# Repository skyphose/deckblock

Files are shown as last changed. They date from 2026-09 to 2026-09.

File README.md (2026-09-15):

# deckblock

a dice and counter tray that lives INSIDE a top-opening deck box, alongside the cards.
one parametric source, two variants.

it was made to fit an ultimate guard boulder 100+. thats the box i own, and every
dimension in it came off that box or off the sleeves that go in it. its also universal,
which is arithmetic rather than a claim: width and height come off the card footprint,
and thats the same in every standard-size deck box. only depth varies between them.

the variants answer "do you carry a coin?", not "which game do you play". the layouts
were named after games for three releases and it was always slightly a lie - nothing in
either is game-specific. people picked the wrong one because they picked by the name on
the box rather than by what they actually carry.

fit spec: the slab is 67 x 91 x 18.6 mm. it drops into any top-opening deck box with an
interior at least 67 mm wide, 91 mm tall, with 19 mm of depth to spare.

the height is taken from the SLEEVE rather than the box. an ultimate guard katana
standard sleeve is 66 x 91 mm, and every deck in the box is that tall. so the test is
whether your sleeved cards stand up in it - if they do, so does this. taking the height
from the sleeve also puts the slab's top edge level with the top of the cards rather than
below them. it doesnt sink away from the opening.

the width is that sleeve plus 1 mm (`over_w`). the slab only has to fit the box, not sit
beside a card, and every millimeter there lands in the cavity field. that makes
width the one dimension still bounded by the REPORTED box interior rather than a
published figure. 0.75 mm of clearance per side, so a box 1 mm narrower than reported
still fits and one 1.5 mm narrower doesnt. set `over_w = 0` to sit exactly on the sleeve.

width and height are set by the card footprint and so are effectivley constant across
standard-size boxes. only depth varies. dimensioned around an ultimate guard boulder 100+
(interior about 68.5 x 67.5 x 93 mm), which is where the fit gaps come from. that box is
the only one whose interior figure has been looked up, and even that one is a reported
number rather than an official spec. treat the three numbers above as the thing to
measure against, not the brand.

| variant | holds | slab depth | card depth left |
|---|---|---|---|
| `nocoin` | 6 x 16 mm d6 + a 43.8 mm open bay for tokens | 18.6 mm | 48.9 mm |
| `coin` | 7 x 16 mm d6 + a ⌀38 mm flip-coin well, no bay | 18.6 mm | 48.9 mm |

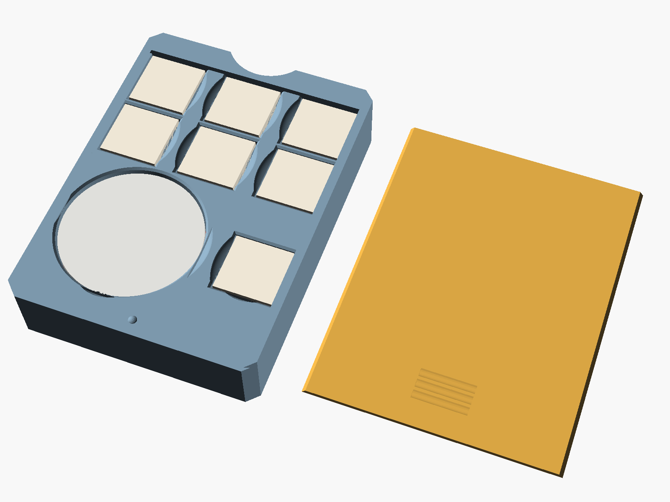
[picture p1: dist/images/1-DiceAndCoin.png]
the coin variant


## how it works

a slab that spans the full interior width and height of the case but only about 19 mm
of its roughly 67 mm depth. because its captured on all four sides by the case walls, it
cant shift, tip or rattle. a sliding lid encloses the contents.

the lid exits the BOTTOM edge. once the slab is seated in the case, the floor of the deck
box sits across that edge and blocks the lid. it can only come off once you lift the
slab out, using the finger scoop in the top rail.

```
                 slab           +-- 48.9 mm left for cards --+
   box wall  | <-18.6 mm-> |    |                              |  box wall
             |[d6][d6][d6] |    |   sideboard                  |
             |[d6][d6][d6] |    |                              |
             | open bay    |    |                              |
```

## the depth budget is the whole design

18.6 mm is the practical floor for an enclosed 16 mm die - the die itself is 86% of it:

```
  0.8  floor (with a push-out hole under each cavity)
 16.3  cavity depth      <- 16.0 of this is the die
  1.5  lid + its groove, running out to the top face
 -----
 18.6  mm
```

every millimeter added here is a millimeter taken from the card stack. thats why the
round wells are 16.3 mm deep and no deeper: a deeper well buys counter capacity you
wont use, and a double-sleeved 60-card deck needs roughly 45 mm. both variants therefore
land on the same 18.6 mm.

pick by whats in your bag, not by which game you play - nothing in either layout is
game-specific. mtg and riftbound players almost always want the no-coin one. pokemon
players almost always want the coin one.

the coin variant has MORE dice, not fewer. a round well's diameter sets the height of the
whole band it sits in. so the coin's band is 38.8 mm tall and leaves 22.2 mm of the 61 mm
interior beside it - exactly enough for a seventh die rather than dead space. the coin
costs the bay, not the dice.

there used to be a fourth line here: 1.4 mm of "retaining lip above the groove". it was
doing nothing. the groove is a DOVETAIL. the lid is trapezoidal and wide at its base, so
what stops it lifting out is the taper of the groove beside it, not material on top of
it. running the groove out to the top face costs nothing srtucturally, takes 1.4 mm
straight off the slab, and brings the lid flush with the frame.

a polyhedral die is cheaper than it looks. one resting on a face is only 0.795 x its
vertex-to-vertex width tall. so a 20 mm d20 in a custom layout stands 15.9 mm and clears
the standard 16.3 mm well without deepening anything. if you build a custom profile
around a d20, use `well(d20_size, d20_depth)` - `d20_depth` applies that rule for you
instead of the naive full width.

## the pokemon coin well

this was wrong for a long time. worth recording. the well was built around
`coin_d = 26.0`, assumed, not looked up. official pokemon coins run 29.8-51.6 mm. the
common modern flip coin is the 34 mm "large", the bigger authorized collectible is 38 mm,
and 25 mm compact ones and 51 mm jumbos sit at the extremes. a 26.8 mm well took only the
smallest of them, so for most people the coin wouldnt go in.

its now built for `coin_d = 38.0` - a ⌀38.8 mm well, which swallows every size below it:

| coin | ⌀ | fits |
|---|---|---|
| pokemon compact flip coin | ~25 mm | yes |
| us quarter | 24.26 mm | yes |
| pokemon LARGE flip coin (the common one) | 34 mm | yes |
| pokemon large collectible | 38 mm | yes |
| us half dollar | 30.61 mm | yes |
| pokemon jumbo | 51 mm | no - see below |

### what the coin costs

a round well's DIAMETER sets the height of the whole band it sits in. so a 38.8 mm well
is expensive twice over: its 38.8 mm tall, and it leaves only 22.2 mm of the 61 mm
interior beside it. two consequences:

- the coin gets one companion, not two. coin + two ⌀13.8 counter wells comes to 66.4 mm
  in a 61 mm interior - impossible at any wall thickness. its paired with the LARGE
  counter well rather than a small one, because that uses the leftover width better: a
  4.4 mm gap instead of 8.4 mm of dead space.
- the small counter well moved up to join the dice, whose band is only 16.8 mm tall and
  had width going spare. both counter sizes survive. nothing was dropped.

measured, at `div_wall = 1.6`:

| layout | bay | tightest gap | |
|---|---|---|---|
| `[small, d6, d6]` / `[coin, large]` | 15.8 mm | 4.4 mm | shipped |
| `[large, d6, d6]` / `[coin, small]` | 14.8 mm | 4.8 mm | 8.4 mm of dead width |
| `[small, lg, d6]` / `[coin, d6]` | 14.8 mm | 5.4 mm | loses a die |
| `[large, d6, d6]` / `[coin, small, small]` | 17.9 mm | -2.7 mm | impossible |

the bay pays for it: 25.9 mm before, 15.8 mm now. a 25.4 mm status marker no longer lies
flat in it. thats the delliberate trade - a coin well that fits the coin most people own
beats a bay sized for a marker you could keep in the open.

### jumbo coins cant be housed

a 51 mm jumbo needs a 51.8 mm well. that exceeds the tallest band the slab can hold once
the dice row and the bay's bottom wall are accounted for. it doesnt fit loose in the bay
either - the largest bay any layout can offer is 41.9 mm. nothing in a 67 x 91 slab takes
one. if you own a jumbo, it lives outside the insert.

### internal dividers run thinner than the perimeter

`div_wall = 1.6` separates the two bands, against `wall = 2.5` for the outer shell. the
perimeter cant thin, the lid groove already cuts 1.2 mm into it and leaves 1.3 mm. a
divider between two cavities carries no load, so it buys 0.9 mm of bay.

one divider is excluded: the last band's gap to the bay carries the detent bump, whose
footprint is 2.30 mm across. on a 1.6 mm divider the dome would overhang its own wall
and need support, so that gap stays at `wall`.

### what this insert deliberately doesnt do

some games want a second card group at the table - riftbound's rune deck and battlefields
are the clearest case. the obvious idea is a card slot in the slab for them. it cant be
done in this case. the slab is 91 mm tall, exactly a sleeve, and a sleeved standard card
is the same 91 mm. the cards are 3 mm too tall for any slot the slab could contain, in
any orientation. sixteen sleeved cards also want about 11 mm of the depth budget, which
is well over half the 18.6 mm the whole insert gets. keep the runes and battlefields
banded in the main card compartmnet.

## measure before you print

theres no test print at this size to fall back on, so the numbers have to be right up
front. two of them arent measurements:

- the case interior (68.5 x 67.5 x 93 mm) is a widely-reported figure, not an official
  one. check yours before committing to a 3-hour body.
- the counter diameters are plausible values for common accessories, not calipered
  readings of yours.

everything that governs fit is a single named parameter at the top of `deckblock.scad`,
so a miss is a one-number change and a re-render:

| symptom | change |
|---|---|
| dice too tight / too loose | `die_clearance` (0.8 total, ±0.2) |
| counters too tight / too loose | `well_clearance` (0.8 total, ±0.2) |
| counters are the wrong size | `ctr_small_d` / `ctr_large_d` / `coin_d` / `d20_size` |
| lid binds / too loose | `lid_side_clearance` (0.5 total, ±0.2) |
| lid rattles vertically | `lid_vert_clearance` (0.3) |
| detent too weak / too strong | `detent_h` (0.60), see below. set to 0 to remove it |

one clearance parameter governs every cell of a kind: `die_clearance` for square pockets,
`well_clearance` for round wells. so if your SMALLEST counters bind, thats
`well_clearance`, not the layout.

the lid is the cheap part to print: about 20 minutes and 5.8 cm³. it wont tell you
whether the slab fits your case. it does tell you whether the groove clearances and the
detent are right, since its the same extrusion on every profile.

## rendering

```sh
./render.sh              # both variants -> stl/<variant>/ + preview_<variant>.png
./render.sh coin         # just one
```

or open `deckblock.scad` in the openscad gui and pick `variant` in the customizer panel.
installed here via `brew install --cask openscad@snapshot` (the stable `openscad` cask
is disabled on macos - it fails the gatekeeper check).

## print settings

print FLAT, open side up, exactly as the stl is oriented. verified on every body: zero
downward-facing facets steeper than 45°, and the only overhang on a lid is its 2.87 mm²
detent dimple. no supports anywhere.

| | body | lid |
|---|---|---|
| layer height | 0.20 mm | 0.16 mm |
| walls | 3 | 4 |
| infill | 15% gyroid | 100% |
| supports | none | none |

solid volumes:

| variant | body | lid |
|---|---|---|
| `nocoin` | 31.6 cm³ | 6.3 cm³ |
| `coin` | 50.7 cm³ | 6.3 cm³ |

down 12% across the bodies from a space-saving pass. the top rail cut from 10 mm to 7,
the floor from 1.0 to 0.8, and every divider BETWEEN two bands thinned from `wall` to
`div_wall`. each of those also hands the space back to the bay.

with the settings above expect roughly 24-30 g / 2.5-3 h for the nocoin body and about
7 g / 20 min for a lid. scale the coin body by volume and confirm in orca.

the only feature on any part that overhangs is the lid's single 0.35 mm detent dimple
(2.87 mm², measured, on every profile). it bridges over about 2.9 mm in about three
layers and needs no support. every BODY measures exactly 0.00 mm² of unsupported facet.
the pinch notches keep it that way by coonstruction: theyre cut downward from the cavity
mouth, so nothing is ever left spanning over one.

tightest wall: 3.3 mm, between the coin well and its neighbor in the `coin` variant's
third band. thats eight perimeters at 0.4 mm and it thickens immediately either side of
the tangent line. nothing in any shipped profile is thinner.

## one lid fits both

both lids are the SAME file - identical md5, not merely similar, and its checked rather
than assumed: `tools/build_all.sh` compares the md5s on every build.

they used to differ by the position of one dimple. the detent bump sat on the divider
between the last band and the bay, and that divider lands somewhere different in every
layout. any lid would slide in any body, but only its own would click.

the detent is now anchored to the BOTTOM wall, the one piece of solid material every
layout has in the same place, at `detent_y = 4.0`. the lid no longer references the band
list at all, so `insert_lid()` doesnt take one.

the bottom wall is only `wall` thick. that isnt enough to seat the bump and still keep
the lid's mating dimple clear of the lid's open end. so a small boss tihckens it locally:
11 mm wide, reaching 3 mm into the bay. that costs about 0.5 cm³ and a sliver of the
bay's bottom edge - a fair price for one lid instead of three. the lid's grip grooves
moved from y = 4 to y = 8 to stay clear of the dimple, which sits at y = 3.5.

## getting things back out

a pocket sized to hold a die also holds onto it. two features fix that, and both are
sized by rule rather than by eye.

### push-out holes

a hole through the floor behind every cavity, so you push a die or a counter stack out
from behind with a fingertip instead of picking at it.

the hole is sized from the cavity, not to a fixed number. it used to be capped at 14 mm,
so the hole behind a ⌀38.8 mm coin well was the same size as the one behind a ⌀17.8 mm
counter well. the coin sat on a 12.4 mm ledge with a fingertip-sized hole in the middle
of it. you could press the coin, but not tip it. now:

```
hole = min( cavity × pushout_frac ,  cavity − 2 × pushout_ledge )
```

`pushout_frac = 0.80` scales the hole with the cavity. `pushout_ledge = 1.6` is a floor
that takes over on small cavities, where the fraction alone would leave too little
material.

| cavity | old | new | ledge under contents | limited by |
|---|---|---|---|---|
| ⌀13.8 small counter well | 10.6 | 10.6 | 1.20 mm | ledge |
| 16.8 mm d6 pocket | 13.6 | 13.44 | 1.28 mm | proportion |
| ⌀17.8 large counter well | 14.0 | 14.24 | 1.38 mm | proportion |
| ⌀20.8 vp die well | 14.0 | 16.64 | 1.68 mm | proportion |
| ⌀38.8 coin well | 14.0 | 31.04 | 3.48 mm | proportion |

`pushout_d` survives as an optional absolute cap, deefaulting to 0 (none).

nothing can fall through, because the contents are captured sideways by the cavity
walls. a 16 mm die over a 13.44 mm hole still rests on all four corners of its face and
can only move ±0.4 mm. a 38 mm coin over a 31.04 mm hole keeps 3.5 mm of ledge all the
way round.

### pinch cutouts

a dish taken out of the divider beside each cavity. it works WITH the push-out hole
rather than instead of it. push the die up from behind, and the dish is what lets you
get a finger onto its side and catch it.

the shape is a segment of a large circle, not a round-bottomed slot. `notch_arc = 60`
sets how much of that circle is used, a sixth. the radius follows from the bite, so the
sweep stays long and smooth instead of becoming a tight bowl. `notch_depth = 4.5` is how
far it reaches down the side of the die.

each edge is sized against the divider its actually cutting. a divider between two
cavities is bitten from both sides, so each side takes half the spare material. a divider
facing the open bay is bitten once and takes all of it. every divider necks to exactly
`notch_min_wall = 1.2` mm at the notch, whatever it started at. thats the most the cut
can take without going thinner than one number you control.

in practice the side edges, cut into 3.3-6.8 mm dividers, get bites of 1.05-2.2 mm. the
cross-band edges sit on the 1.6 mm `div_wall` divider and would get 0.2 mm, which is a
scratch rather than a grip. so dishes below 0.3 mm arent generated at all. thats the
deliberate trade for thin dividers: the space goes to the bay, and the grip lives on the
side edges.

two properties worth knowing:

- they cant introduce an overhang. the dish is an ellipsoid whose center sits
  `notch_ease` ABOVE the cavity mouth. every scrap of material is below the mouth, hence
  below the center, so every cut surface faces upward. thats also what eases the rim
  instead of leaving a 90° lip. every body measures 0.00 mm² unsupported.
- they cant breach a wall. the full set is clipped to the divider field, inside the
  outer walls and below the top rail. a notch that would break out erases itself
  instead of being a bug. each dish is aditionally clipped to its own side of the edge,
  so it cant reach across a cavity and nibble the divider opposite.

the subtree is wrapped in `render()`. without it the preview's csg normalizer explodes on
the clipped dishes and gives up. it makes no difference to the exported geometry.

set `pinch_notch = false` to omit them entirely.

## layouts

each profile is a stack of bands, laid out top-down under the finger rail. whatever
height is left at the bottom becomes the open bay. within a band, gaps are derived to
fill the interior width.

```
band = [ [cell, cell, ...], gap_after, cell_gap ]
cell = ["sq", w, h, depth]     rect pocket (dice, card-shaped markers)
     | ["rd", d, d, depth]     round well  (counters, coins, a d20)
```

so a new layout is a few lines. set `variant = "custom"` and edit `custom_bands`:

```scad
custom_bands = [
    [[ d6(), d6(), d6() ],                                 div_wall, 0],
    [[ well(ctr_small_d, well_depth), well(coin_d, 16.3) ], wall,    0],
];
```

`cell_gap = 0` spreads the cells to fill the width. a positive value uses that fixed gap
and centers the block instead.

| variant | band 1 | band 2 | band 3 | bay |
|---|---|---|---|---|
| `nocoin` | 3 x d6 | 3 x d6 | none | 43.8 mm |
| `coin` | 3 x d6 | 3 x d6 | ⌀38.8 coin well + d6 | none |

the bay is one undivided space. it used to carry a center rib to support the lid
mid-span. that bought very little, since the lid is captured in the side grooves along
its whole length. and it cost a lot: it turned one pocket you can actually reach into two
narrow ones. set `bay_rib = true` to bring it back.

## publishing

`./prep_release.sh` rebuilds `dist/` from scratch - stls, 3mfs, images, source and docs,
with the models named so they sort into the order you should print them:

```
dist/
  models-stl/  Deckblock_<Variant>_{1-body,2-lid}.stl
  models-3mf/  the same parts as 3MF (MakerWorld prefers these)
  images/      1-<Variant>.png, 2-fits-in-case.png, 3-push-out-holes.png
  source/      deckblock.scad + the render scripts
  README.txt   LICENSE.txt
```

every exported stl is run through `tools/meshcheck.py --strip`, which asserts the mesh is
a closed 2-manifold: every edge shared by exactly two triangles, no zero-area facets. if
any turn up it rewrites the file without them. three checks worth knowing:

- the nocoin body comes out genus 6 and the coin body genus 8, one per cavity. thats an
  independent coonfirmation that every cavity got its push-out tunnel. if a hole ever
  failed to cut, the genus would drop.
- the bodies carry zero-area facets, 18 on `nocoin` and 16 on `coin`, and the published
  stls have them stripped. they come
  from the flush groove: with `cap_t = 0` the groove's top edge lands exactly on the
  slab's top face. the mesher leaves a few degenerate facets along that coincidence. they
  sit on an already-closed mesh - 0 open edges, 0 non-manifold edges with them discarded
  - so removing them is provably safe. running the cut past the top face along the same
  taper was tried and made it worse (8 -> 12), so the strip stays.
- 3mf round-trips exactly. re-importing `Deckblock_Dice_1-body.3mf` gives 10056 triangles
  and 31.593 cm³, the same as the stl. the 3mfs are NOT stripped, though: meshcheck reads
  stl only, so `prep_release.sh` strips the stls and the 3mfs ship with their degenerate
  facets. slicers dont care, but if youre diffing the two formats, thats the
  difference.

`LISTING.md` holds the listing copy. the license is CC BY-NC-SA 4.0, set in
`LICENSE.txt` - change that file and the listing's license field together if you want
something else.

## what has been printed

not this exact size. the prints in `photos/` are an earlier build at 66 x 88, before the
slab took its height from the sleeve. everything else about them is what ships: the flush
lid, the arc notches, the push-out holes, the bottom-wall detent, the 18.6 mm depth
budget. so the geometry is proven and the outside size isnt, and theres no cheap coupon
to catch a bad fit. print one body and lid and check them in a real box before you trust
the fit.

an earlier prototype than that was printed too, and its the reason the detent got
rebuilt. it was reported as doing nothing, which turned out to be exactly right and
provable from the numbers.

## dimensions used

| | value | source |
|---|---|---|
| case exterior | 76 x 75 x 98.5 mm | ultimate guard product data |
| case interior | 68.5 x 67.5 x 93 mm | ultimate guard boulder 100+. reported, not official - measure yours |
| slab | 67 x 91 x 18.6 mm | 0.75 mm/side across the width, 1.0 mm/side up the height |
| die pocket | 16.8 mm sq x 16.3 deep | 0.4 mm/side around a 16.0 mm die |
| lid in groove | 0.25 mm/side, 0.3 mm vertical | derived from the groove geometry. printed once, not measured back |

the counter diameters are assumptions, not measurements. `ctr_small_d = 13.0`,
`ctr_large_d = 17.0` are plausible figures for common accesories, but nobody has put
calipers on yours. `coin_d = 38.0` isnt a guess. its the larger authorized pokemon coin
size, and the well takes every smaller one. measure them and edit the four numbers
before you print a body.

width and height are set by the card footprint and should be the SAME across the boulder
sizes (60+/80+/100+/133+). only the depth budget changes, and only `box_int_d` in the
report line depends on it. that reasoning is untested on anything but the 100+.

## files

| file | what |
|---|---|
| `deckblock.scad` | parametric source - edit this, everything else is generated |
| `render.sh` | renders every profile |
| `preview.scad` | preview render only, not printable |
| `stl/<variant>/` | `<variant>_body.stl`, `<variant>_lid.stl` - working output |
| `prep_release.sh` | builds `dist/`, the upload bundle |
| `tools/meshcheck.py` | watertight / manifold validator, with `--strip` to drop zero-area facets |
| `context.scad` | exploded in-case render for the listing, not printable |
| `LISTING.md` | paste-ready listing copy - the single source of truth for the description |
| `photos/` | prints of an earlier build, with an index saying which shots still represent what ships |
| `LICENSE.txt`, `dist_README.txt` | shipped inside `dist/` |
| `dist/` | the upload bundle. regenerated from scratch by `prep_release.sh` |
| ~~`boulder_deckblock.scad`, `stl/insert_*.stl`~~ | deleted from the repo. the original mtg-only source and its stls - they were the reference the regression check differenced against. see the note under that check. |

### other checks

- overhangs. every body measures 0.00 mm² of unsupported facet. a lid measures 2.87 mm²,
  which is its detent dimple and matches π x 0.963² = 2.91.
- wall breach. a probe solid covering both side walls and the bottom wall, below the
  groove and clear of the corner reliefs and finger scoop, was differenced against each
  body. nothing remained on any profile - no notch reaches an outer wall.

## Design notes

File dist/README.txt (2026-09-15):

================================================================================
 deckblock - a dice and counter insert for top-opening deck boxes
 made for the ultimate guard boulder 100+      openscad source included
================================================================================

WHAT IT IS
  a slab that fills the dead space in front of your deck. it spans the full
  interior width and height of the box but only 18.6 mm of its depth, so its
  captured on all four sides and cant rattle. it still leaves 48.9 mm for
  cards, which takes a double-sleeved 60-card deck with room over.

  a lid slides across the top to keep everything in. the lid exits the BOTTOM
  edge, so once the slab is seated the floor of the deck box sits across that
  edge and blocks it. it cant open in your bag.

  both faces are flat. the lid sits flush with the frame, 0.3 mm down, which is
  only the clearance it needs to slide. its thumb grip is cut into it rather
  than raised off it. nothing stands proud to catch your cards.

--------------------------------------------------------------------------------
WILL IT FIT YOUR BOX?
--------------------------------------------------------------------------------
  the slab is  67 x 91 x 18.6 mm.

  it drops into any top-opening deck box whose interior is at least 67 mm wide,
  91 mm tall, with 19 mm of depth to spare.

  it was made for an ultimate guard boulder 100+, interior about
  68.5 x 67.5 x 93 mm, and thats where the 2.5 mm and 5 mm fit gaps come from.
  it fits the rest by arithmetic rather than by brand: width and height come off
  the card footprint, and thats the same in every standard-size deck box. only
  depth varies between them.

  the height is taken from the SLEEVE, not the box. an ultimate guard katana
  standard sleeve is 66 x 91 mm, and every deck in the box is that tall. if your
  sleeved cards stand up in it, so does this.

  untested at this size. i printed an earlier build at 66 x 88, not this one. so
  measure the inside of yours and compare against those three numbers.

--------------------------------------------------------------------------------
BEFORE YOU PRINT A BODY
--------------------------------------------------------------------------------
  two numbers here are assumptions, not measurements:

    - your box's interior. mnaufacturers rarely publish interior dimensions and
      the figure above is a reported one. measure yours.
    - your counters. ctr_small_d = 13.0 and ctr_large_d = 17.0 are plausible for
      common accesories, not calipered readings of yours. the coin well is
      sized to the 38 mm authorized pokemon coin and takes every smaller one,
      including the common 34 mm "large" flip coin. a 51 mm jumbo wont fit.

  every clearance is a single named parameter at the top of the .scad file, so a
  miss is one number and a re-render:

    die_clearance        dice too tight / too loose      (0.8 total)
    well_clearance       counters too tight / too loose  (0.8 total)
    ctr_small_d etc.     counters are the wrong size
    lid_side_clearance   lid binds / too loose           (0.5 total)
    lid_vert_clearance   lid rattles vertically          (0.3)
    detent_h             click too weak / too strong     (0.6)

  the lid is the cheap part to print, about 20 minutes. it wont tell you whether
  the slab fits your box. it does tell you whether the groove clearances and the
  detent feel right, and its the same part on both variants.

--------------------------------------------------------------------------------
PRINTING
--------------------------------------------------------------------------------
  orientation   exactly as the models are oriented. flat, open side up.
  supports      NONE. verified: zero downward-facing facets steeper than 45
                degrees on every body.
  body          0.20 mm layers, 3 walls, 15% infill
  lid           0.16 mm layers, 4 walls, 100% infill  (its only 1.2 mm thick)
  material      pla or petg. petg slides a little more smoothly.

  print one body + one lid. both variants ship the SAME lid, one file not two.
  the detent is anchored to the bottom wall rather than to each layout's
  dividers, so any lid slides, clicks and holds in any body.

--------------------------------------------------------------------------------
GETTING PIECES BACK OUT
--------------------------------------------------------------------------------
  every cavity has a hole through the floor behind it, so you push a die or a
  counter stack out from behind instead of picking at it. the hole is scaled to
  the cavity: 13.4 mm behind a d6, 31 mm behind the coin.

  the dividers also carry shallow arc cutouts, so you can get a finger onto the
  side of a die and catch it as it comes up.

--------------------------------------------------------------------------------
FILES
--------------------------------------------------------------------------------
  models-stl/   stls, numbered in the order to print them
  models-3mf/   the same parts as 3mf
  images/       renders
  source/       openscad source, see below
  LICENSE.txt   CC BY-NC-SA 4.0

--------------------------------------------------------------------------------
MAKING YOUR OWN LAYOUT
--------------------------------------------------------------------------------
  source/deckblock.scad is fully parametric and works in the openscad
  customizer. `variant` and `part` are dropdowns. a layout is a list of bands:

      nocoin_bands = [
          [[ d6(), d6(), d6() ], div_wall, 0],
          [[ d6(), d6(), d6() ], wall,    0],
      ];

  cells are d6(size), well(diameter, depth) or slot(w, h, depth). set
  `variant = "custom"` and edit `custom_bands`. gaps, wall thicknesses, the lid
  and its groove, the push-out holes, the pinch cutouts and the open bay at the
  bottom are all derived for you.

================================================================================

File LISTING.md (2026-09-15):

# listing copy

paste-ready text for printables / makerworld / thingiverse. everything below the line is
the listing itself.

---

## title

> deckblock - a dice insert made for the ultimate guard boulder, fits any top-opening
> deck box, with or without a coin well

## summary / one-liner

> 67 x 91 x 18.6 mm sliding-lid dice tray, made for the ultimate guard boulder 100+ and
> sized to fit any standard top-opening deck box. no supports, flat on both faces. two
> variants, coin well or not. parametric openscad source included.

## tags

`deckblock` `deck box` `deck box insert` `dice tray` `dice insert` `universal` `mtg`
`magic the gathering` `pokemon` `riftbound` `tcg` `card game` `organizer` `coin holder`
`ultimate guard` `boulder` `gamegenic` `dragon shield` `parametric` `openscad`
`customizer` `no supports` `sliding lid`

## category

gadgets -> board games / tabletop accessories

## license

CC BY-NC-SA 4.0

---

## description

### the dead space in front of your deck

a 100+ capacity deck box is far deeper than the deck you keep in it. this is a slab that
fills the gap. it spans the full interior width and height of the box but only 18.6 mm
of its depth. its captured on all four sides and cant shift, tip or rattle. no glue, no
clips, no friction fit to tune.

it leaves 48.9 mm for cards. a double-sleeved 60-card deck is about 45 mm, so that fits
with room over. the slab takes 18.6 mm of the 67.5 mm interior, about a quarter, so a
100+ becomes something nearer a 70+. if you fill a deck box to the brim, this isnt for
you.

### will it fit my box?

it was made for an ultimate guard boulder 100+, which is the box every dimension came
off. it fits the rest by arithmetic rather than by brand: width and height are set by the
card footprint, and thats the same in every standard-size deck box. only the depth
differs. so the question is whether yours has the room:

> the slab is 67 x 91 x 18.6 mm.
> it drops into any top-opening vertical deck box with an interior at least 67 mm wide,
> 91 mm tall, and 19 mm of depth to spare.

untested at this size. i printed an earlier build at 66 x 88, not this one. so measure
the inside of your box and compare. most 100+ capacity top-loaders clear this comfortably. 50+ and
80+ boxes will take the slab but leave you correspondingly less deck. it was dimensioned
around an ultimate guard boulder 100+ (interior about 68.5 x 67.5 x 93 mm), which is
where the 2.5 mm and 5 mm fit gaps come from.

if your box is a little larger inside, the slab sits with more slack - raise `fit_gap_w`
/ `fit_gap_h` in the source and re-render.

### flat on both faces

the lid sits flush with the frame - 0.3 mm down, which is only the clearance it needs to
slide. the thumb grip is cut INTO the lid rather than raised off it, so nothing stands
proud to catch your card stack. the back face is flat apart from the push-out holes.

### the lid cant open in your bag

a 1.2 mm lid slides in a dovetailed groove and clicks over a detent. the part that
matters is which way it goes: the lid exits the BOTTOM edge. once the slab is seated,
the floor of the deck box sits across that edge and blocks it. theres no orientaiton in
which it can slide open while its in the box. lift the slab out by the finger scoop in
the top rail and it opens normally.

### two variants

| variant | holds |
|---|---|
| dice | 6 x 16 mm d6 and a 43.8 mm open bay for tokens, markers and spares |
| dice + coin | 7 x 16 mm d6 and a ⌀38 mm flip-coin well |

pick by whats in your bag, not by which game you play - nothing in either layout is
game-specific. mtg and riftbound players almost always want the no-coin one. pokemon
players almost always want the coin one.

the coin version has MORE dice, not fewer. a round well's diameter sets the height of
the whole band it sits in. so the coin's band is 38.8 mm tall and leaves 22.2 mm of the
61 mm interior beside it - exactly enough for a seventh die rather than dead space. the
coin costs the bay, not the dice.

a 51 mm jumbo coin cant be housed at all - not in a well, and not loose either. nothing
in a 67 x 91 slab will take one.

### things come back out again

- push-out holes through the floor behind every cavity. push a die or a counter stack
  out from behind with a fiingertip rather than picking at it. sized as large as the
  retaining ledge allows, and scaled to the cavity: 13.4 mm behind a d6, 31 mm behind
  the coin. a big flat coin gets tipped out rather than pressed.
- pinch cutouts in the dividers, shaped as a shallow segment of a large circle. you get
  a finger onto the side of a die and catch it as it comes up. each one is sized
  against the divider it cuts, taking the most that divider can give while leaving
  1.2 mm standing.

### printing

orientation: exactly as the models are oriented, flat, open side up. supports: none.
verified numerically, not by eye: zero downward-facing facets steeper than 45° on every
body. pla is fine. petg slides a little more smoothly.

| | body | lid |
|---|---|---|
| layers | 0.20 mm | 0.16 mm |
| walls | 3 | 4 |
| infill | 15% | 100%, its only 1.2 mm thick |

print one body and one lid. both variants ship the SAME lid - one file, not two. the
detent is anchored to the bottom wall rather than to each layout's dividers, so a lid
from any variant slides, clicks and holds in any body.

### make your own layout

the source is one parametric openscad file (`deckblock.scad`) and it works in the customizer - `variant` and
`part` are dropdowns. a layout is a list of bands:

```scad
nocoin_bands = [
    [[ d6(), d6(), d6() ], div_wall, 0],
    [[ d6(), d6(), d6() ], wall,    0],
];
```

cells are `d6(size)`, `well(diameter, depth)` or `slot(w, h, depth)`. set
`variant = "custom"`, edit `custom_bands`, and the gaps, wall thicknesses, lid, groove,
push-outs, pinch cutouts and the open bay are all derived for you. remixes welcome.

### before you print a body

two numbers in the model are assumptions rather than measurements, and both are a
one-line fix:

- your box's interior. published interior dimensions are rare and the figure used here
  is a reported one. measure yours against the spec above.
- your counters. `ctr_small_d = 13.0` and `ctr_large_d = 17.0` are plausible for common
  accessories, not calipered readings of yours. the coin well is sized to the 38 mm
  atuhorized coin and takes every smaller one, including the common 34 mm "large".

every clearance is a single named parameter at the top of the file, so a miss is one
number and a re-render.

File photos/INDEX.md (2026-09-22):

# photos of the printed insert

these are prints of an earlier build: 66 x 88 mm, three game layouts. what ships now is
67 x 91 mm with two variants, coin and no coin. read the mapping note at the bottom
before putting any of these on a listing.

| file | what it shows | reviewed |
|---|---|---|
| `IMG_3814` | the coin layout loaded, coin in its well, damage counters, a die | yes |
| `IMG_3815` | - | not reviewed |
| `IMG_3816` | both bodies, empty, side by side. the clearest shot of the geometry: round wells on one, six square dice pockets with push-out holes on the other | yes |
| `IMG_3817` | - | not reviewed |
| `IMG_3818` | in the deck box beside a sleeved deck. the context shot, showing the insert taking the dead space in front of the cards | yes |
| `IMG_3819` | - | not reviewed |
| `IMG_3820` | - | not reviewed |
| `IMG_3821` | closed box, front on, insert visible through the clear wall | yes |
| `IMG_3822` | six dice loaded, seen through the box from behind, showing the push-out holes doing their job | yes |

## how these map to what ships

- the six-dice-plus-bay layout in these photos is the same arrangement as the `nocoin`
  variant. only the outside size changed, 66 x 88 -> 67 x 91, so those shots are
  representative.
- the coin layout in these photos is NOT the `coin` variant. the old one had a coin well,
  two counter wells and two dice. `coin` is seven dice plus the well, with no counter
  wells at all. a photo of the old one would show a layout nobody can download.

## lighting

shot under blue/purple rgb. the filament is blue but reads violet, and the white balance
is a long way off. worth reshooting under neutral light before these go on a listing.

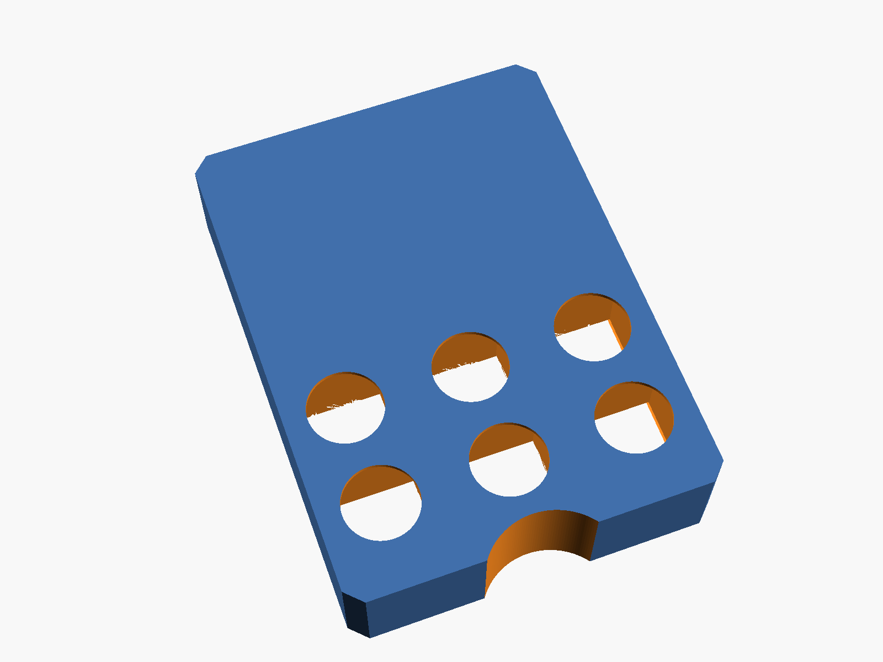
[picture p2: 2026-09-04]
dist/images/3-push-out-holes.png

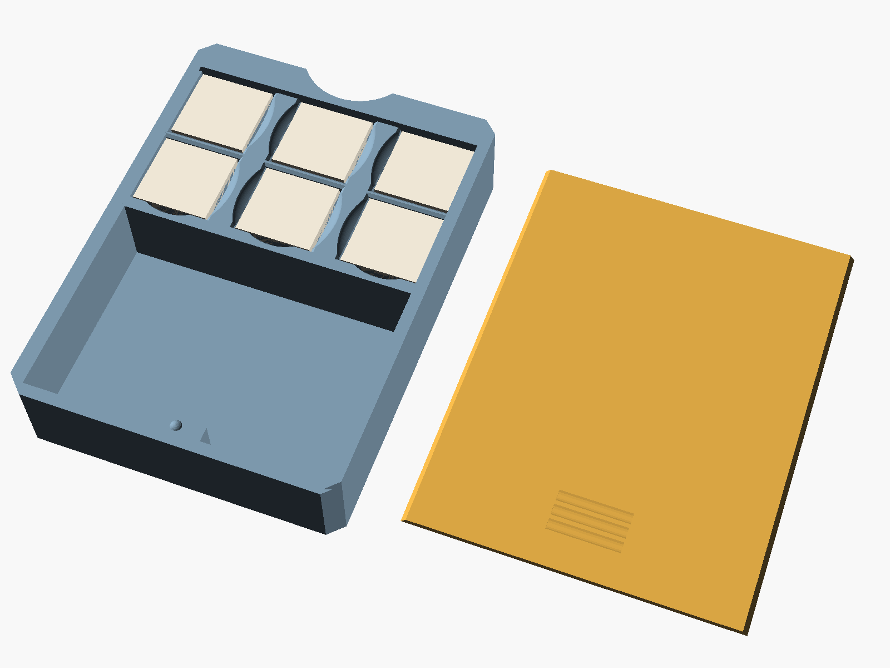
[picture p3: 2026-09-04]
dist/images/1-Dice.png

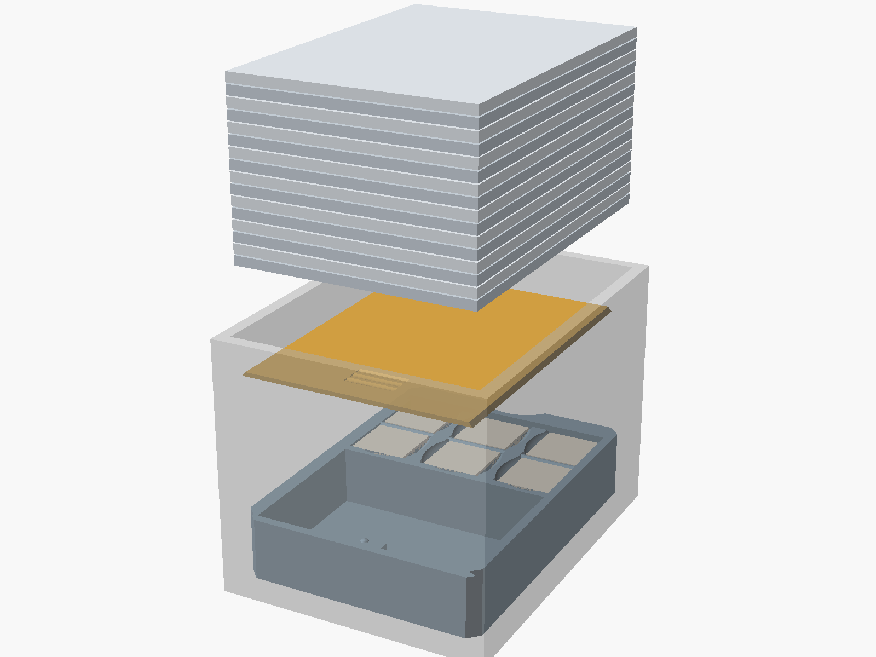
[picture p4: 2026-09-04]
dist/images/2-fits-in-case.png

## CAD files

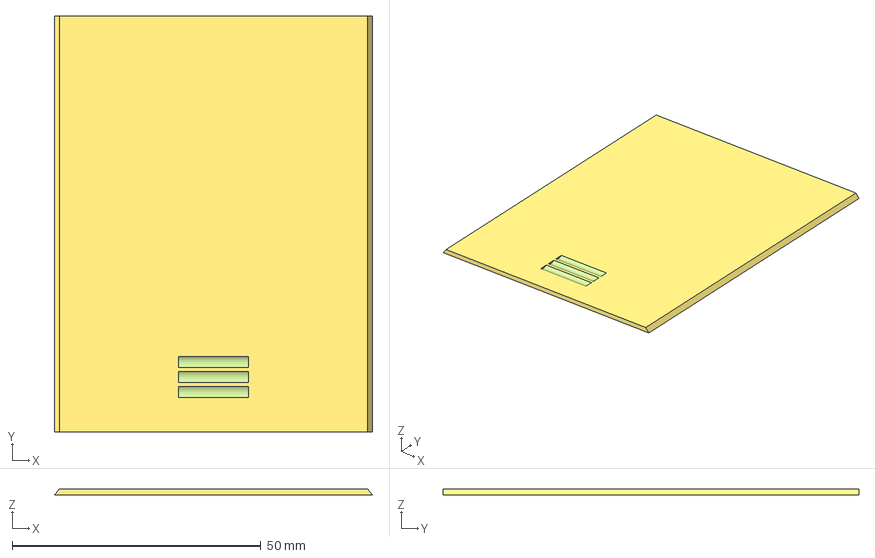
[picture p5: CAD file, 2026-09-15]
dist/models-3mf/Deckblock_DiceAndCoin_2-lid.3mf
63.9 x 83.5 x 1.20 mm

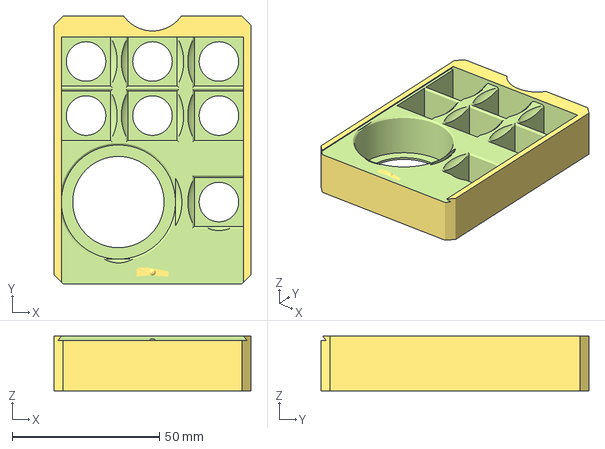
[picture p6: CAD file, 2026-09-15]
dist/models-3mf/Deckblock_DiceAndCoin_1-body.3mf
67.0 x 91.0 x 18.6 mm

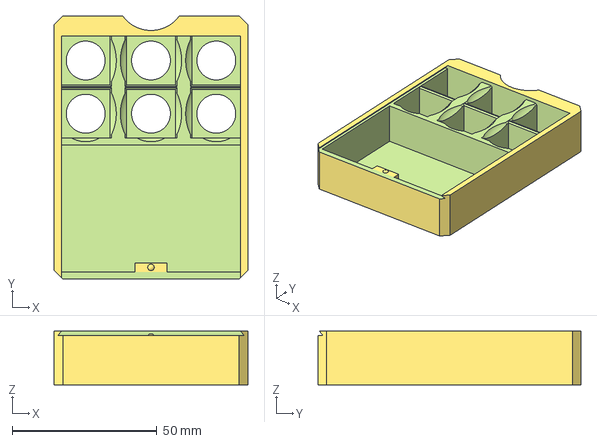
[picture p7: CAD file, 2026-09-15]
dist/models-3mf/Deckblock_Dice_1-body.3mf
67.0 x 91.0 x 18.6 mm

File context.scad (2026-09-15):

// listing explainer: what the insert is for. the slab takes only ~20 mm of the
// case's ~67 mm depth. the deck shown above it is what still fits behind.
// NOT a printable part.
//   openscad -D 'variant="nocoin"' -D 'part="none"' -o context.png context.scad
include <deckblock.scad>

deck_lift = 86;     // deck exploded away so it doesnt hide the insert
ct = 3.5;
ox = -(box_int_w - slab_w) / 2;
oy = -(box_int_h - slab_h) / 2;

// the deck case, ghosted.
%translate([ox - ct, oy - ct, -ct])
    difference() {
        cube([box_int_w + 2*ct, box_int_h + 2*ct, box_int_d + ct]);
        translate([ct, ct, ct]) cube([box_int_w, box_int_h, box_int_d + 1]);
    }

// the deck that still fits behind the insert: 47.3 mm of double-sleeved cards.
deck_t = box_int_d - D - 1.0;
for (i = [0 : 15])
    color(i % 2 ? "#e6ebf1" : "#ccd5de")
        translate([ox + 1.5, oy + 1.0, deck_lift + i * deck_t / 16])
            cube([box_int_w - 3, box_int_h - 2, deck_t / 16 - 0.35]);

color("#7d99ad") insert_body(bands, slab_w, slab_h, top_rail, scoop_depth);
color("#d8a13a", 0.95) translate([0, 0, 40]) insert_lid(slab_w, slab_h, top_rail);

for (k = [0:len(bands)-1], i = [0:len(b_cells(bands[k]))-1]) {
    c  = b_cells(bands[k])[i];
    x  = cell_x(bands[k], slab_w, i);
    y  = cell_y(bands, slab_h, top_rail, k, c);
    z0 = z_groove_bot - c[3];
    if (c[0] == "sq")
        color("#efe7d6") translate([x + c[1]/2, y + c[2]/2, z0 + die_size/2])
            cube(die_size, center = true);
    else
        for (n = [0 : floor(c[3]/3) - 1])
            color(n % 2 ? "#c8524b" : "#e8e8e4")
                translate([x + c[1]/2, y + c[2]/2, z0 + n*3])
                    cylinder(d = c[1] - well_clearance, h = 2.7);
}

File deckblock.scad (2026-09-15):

// ============================================================================
//  deckblock  --  parametric dice and counter insert, two variants
// ----------------------------------------------------------------------------
//  A full-footprint slab that spans the interior width and height of an
//  Ultimate Guard Boulder deck case but only ~19 mm of its ~67 mm depth.
//  Captured on all four sides by the case walls, so it cant shift or rattle.
//
//  The sliding lid exits the BOTTOM edge: once the slab is seated in the case,
//  the floor of the deck box mechanically blocks the lid shut.
//
//  Print flat, open side up. No supports anywhere.
//
//  Set `variant` and `part` below (or override with -D) and export stl.
//
//  67 x 91 mm. the height is taken from the katana sleeve, so the fit test is
//  "do your sleeved cards stand up in the box", and the width is a millimeter
//  over it. two variants, coin and no coin.
// ============================================================================
version = "1.0";

/* [Variant] */
// Which layout to build. The question is whether you carry a coin, not which
// game you play -- see the profiles section for why.
variant = "nocoin"; // [nocoin, coin, custom]

/* [Part to render] */
// Which piece to export.
part = "body"; // [body, lid, all]

/* [Dice] */
die_size      = 16.0;   // across flats of one d6
die_clearance = 0.8;    // TOTAL added to die_size -> 0.4 per side
die_headroom  = 0.3;    // pocket depth above the die, so the lid captures it
// Kept for custom layouts: `well(d20_size, d20_depth)` is the right way to hold
// a d20, and the depth rule below is the non-obvious part.
d20_size      = 22.0;   // WIDEST across your d20 (vertex to vertex) -- measure it

/* [Round wells] */
well_clearance = 0.8;   // TOTAL added to a well diameter -> 0.4 per side

/* [Counters -- VERIFY THESE AGAINST YOUR OWN ACCESSORIES] */
ctr_small_d  = 13.0;    // pokemon 10-damage / generic small counter, disc diameter
ctr_large_d  = 17.0;    // pokemon 50-damage / generic large counter
coin_d       = 38.0;    // flip coin -- see the coin table in the README

// Cavity depths. Keeping every well at the die depth holds the whole slab at
// the proven 20.2 mm, which is what leaves 47.3 mm of card stack behind it.
// Going deeper buys counter capacity you almost certainly dont need and
// costs card room a double-sleeved 60-card deck cant spare.
well_depth   = die_size + die_headroom;   // 16.3 -- counter / coin stack depth

// A d20 resting on a face is only ~0.795 x its vertex-to-vertex width tall
// (icosahedron inradius/circumradius), so the well can be much shallower
// than the die is wide.
d20_depth    = d20_size * 0.795 + 0.5;    // 18.0 for a 22 mm d20

/* [Deck box interior -- Ultimate Guard Boulder] */
// Width and height are set by the card footprint and are the SAME across the
// Boulder sizes (60+/80+/100+/133+); only the depth budget changes.
box_int_w = 68.5;       // interior width  (across the cards)
box_int_h = 93.0;       // interior height (up the cards)
// The slab's height is set from the SLEEVE, not from the box interior, and
// thats the more trustworthy of the two numbers. box_int_h is a reported
// figure rather than a published spec, but an Ultimate Guard Katana standard
// sleeve is 66 x 91 mm and every deck in the box is that tall. So the rule is
// simply: if your sleeved cards stand up in the box, this does too.
//
// It also puts the slab's top edge level with the top of the cards instead of
// 3 mm below it, which is the point -- the insert stops sinking away from the
// opening and is easier to get a finger to.
// The sleeve is the REFERENCE both slab dimensions are stated against, which
// is what keeps them honest: the height is exactly a sleeve, the width is a
// sleeve plus over_w. Before this they came out of box_int_w - fit_gap_w and
// happened to land on 66 mm, which read as intent and was coincidence -- it
// would have drifted silently the moment either of those was edited.
sleeve_w  = 66.0;       // Ultimate Guard Katana, standard size
sleeve_h  = 91.0;
// ...and then a millimeter wider than the sleeve, deliberately. The slab does
// not have to fit BESIDE a card, only inside the box, and the box is 68.5 mm
// across. Every millimeter here lands in the cavity field, where it widens the
// gaps you get a finger into.
//
// This is the one dimension where the reported box interior is load-bearing:
// the height is bounded by the sleeve, which is a published figure, but the
// width is bounded only by box_int_w. At over_w = 1.0 theres 0.75 mm of
// clearance per side, so a box 1 mm narrower than reported still fits and one
// 1.5 mm narrower doesnt. Set it back to 0 to sit exactly on the sleeve.
over_w    = 1.0;
box_int_d = 67.5;       // interior depth  (the card stack) -- 100+; reference only
fit_gap_w = box_int_w - sleeve_w - over_w;   // whatever is left over: 1.5 mm
fit_gap_h = box_int_h - sleeve_h;   // whatever is left over: 2.0 mm

/* [Slab] */
slab_depth    = 0;      // 0 = auto/minimum for the chosen profile.
wall          = 2.5;    // OUTER wall. Do not thin this: the lid groove cuts
                        // lid_groove_depth (1.2) into it, leaving only 1.3 mm.
// Divider between two bands. It carries no structural load -- it only separates
// cavities -- so it runs thinner than the perimeter to buy layout space.
// NOT usable for the last band's gap: that divider carries the detent bump,
// whose footprint is 2.30 mm across and would overhang a thinner wall.
div_wall      = 1.6;
// Material behind the deepest cavity. 0.8 is four layers at 0.20 mm, laid
// straight onto the build plate, and nothing loads it in bending -- a die rests
// on it in compression and is pushed out through the hole in it.
floor_t       = 0.8;
// Material above the lid groove. Zero, deliberately: the groove is a DOVETAIL
// -- the lid is trapezoidal and wide at its base, so what stops it lifting out
// is the taper of the groove beside it, not any material on top of it. Running
// the groove all the way to the top face therefore costs nothing, brings the
// lid flush with the frame, and takes 1.4 mm straight off the slab.
cap_t         = 0.0;
corner_relief = 3.0;    // 45 deg chamfer on the four vertical corners
// Solid rail at the top edge, holding the finger scoop. This is the single
// largest lump of material in the part -- 66 x rail x 18.8 of solid -- so its
// kept only as deep as the scoop needs. scoop_depth (6.0) plus a 2 mm beam
// under its the floor; below that the beam you hook a finger against when
// lifting the slab out gets too thin to trust.
top_rail      = 7.0;

/* [Layout] */
// The open bay is one undivided space by default. Setting this true splits it
// with a center rib, which gives the lid a mid-span support -- at the cost of
// turning one usable pocket into two narrow ones. The lid is captured in the
// side grooves along its whole length, so it doesnt need the rib.
bay_rib   = false;      // center rib across the open bay
lead_in   = 0.6;        // chamfer at the mouth of each cavity

/* [Push-out holes] */
// A hole through the floor behind every cavity: push a die or a counter stack
// out from behind instead of trying to pick it out. Sized as large as the
// retaining ledge allows, capped at a comfortable fingertip.
// The hole is sized FROM the cavity, not to a fixed number. A flat cap made the
// hole behind a 38.8 mm coin the same size as the one behind a 17.8 mm counter
// well, which left the coin sitting on a 12.4 mm ledge with a fingertip-sized
// hole in the middle of it -- you could push it, but not tip it.
pushout_frac  = 0.80;   // hole diameter as a fraction of the cavity
pushout_ledge = 1.6;    // minimum ledge, per side, measured on the CAVITY. Takes
                        // over on small cavities, where the fraction would leave
                        // too little floor. ~1.2 mm under an actual counter.
pushout_d     = 0;      // optional absolute cap; 0 = none

/* [Pinch notches] */
// Scallops in the divider walls beside each cavity, so a die can be pinched
// out from the side rather than only pushed from behind.
pinch_notch    = true;
notch_arc      = 60;    // DEGREES of circle used for the cutout. 60 = a sixth.
                        // Small values give a long, shallow, gentle sweep;
                        // 180 would be a half-round slot.
notch_bite     = 2.2;   // how far it eats into the divider -- a request, not a
                        // promise: each edge is clamped by notch_min_wall.
notch_min_wall = 1.2;   // material that must survive in the divider being cut
notch_depth    = 4.5;   // how far below the cavity mouth it reaches
notch_ease     = 0.8;   // dish center raised above the mouth, so the rim is
                        // eased instead of meeting the surface at 90 degrees
notch_keepout  = 1.5;   // solid kept around the detent bump's footing
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

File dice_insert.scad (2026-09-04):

// ============================================================================
//  TCG Deck-Case Spacer Insert  --  v1.1, parametric, two variants
// ----------------------------------------------------------------------------
//  A full-footprint slab that spans the interior width and height of an
//  Ultimate Guard Boulder deck case but only ~19 mm of its ~67 mm depth.
//  Captured on all four sides by the case walls, so it cannot shift or rattle.
//
//  The sliding lid exits the BOTTOM edge: once the slab is seated in the case,
//  the floor of the deck box mechanically blocks the lid shut.
//
//  Print flat, open side up. No supports anywhere.
//
//  Set `variant` and `part` below (or override with -D) and export STL.
//
//  v1.1  67 x 91 mm: height taken from the Katana sleeve so the fit test is
//        "do your sleeved cards stand up in the box", width a millimetre over
//        it. Two variants, coin and no coin, replacing three game layouts.
//  v1.0  66 x 88 mm, three game layouts.
// ============================================================================
version = "1.1";

/* [Variant] */
// Which layout to build. The question is whether you carry a coin, not which
// game you play -- see the profiles section for why.
variant = "nocoin"; // [nocoin, coin, custom]

/* [Part to render] */
// Which piece to export.
part = "body"; // [body, lid, all]

/* [Dice] */
die_size      = 16.0;   // across flats of one d6
die_clearance = 0.8;    // TOTAL added to die_size -> 0.4 per side
die_headroom  = 0.3;    // pocket depth above the die, so the lid captures it
// Kept for custom layouts: `well(d20_size, d20_depth)` is the right way to hold
// a d20, and the depth rule below is the non-obvious part.
d20_size      = 22.0;   // WIDEST across your d20 (vertex to vertex) -- measure it

/* [Round wells] */
well_clearance = 0.8;   // TOTAL added to a well diameter -> 0.4 per side

/* [Counters -- VERIFY THESE AGAINST YOUR OWN ACCESSORIES] */
ctr_small_d  = 13.0;    // Pokemon 10-damage / generic small counter, disc diameter
ctr_large_d  = 17.0;    // Pokemon 50-damage / generic large counter
coin_d       = 38.0;    // flip coin -- see the coin table in the README

// Cavity depths. Keeping every well at the die depth holds the whole slab at
// the proven 20.2 mm, which is what leaves 47.3 mm of card stack behind it.
// Going deeper buys counter capacity you almost certainly do not need and
// costs card room a double-sleeved 60-card deck cannot spare.
well_depth   = die_size + die_headroom;   // 16.3 -- counter / coin stack depth

// A d20 resting on a face is only ~0.795 x its vertex-to-vertex width tall
// (icosahedron inradius/circumradius), so the well can be much shallower
// than the die is wide.
d20_depth    = d20_size * 0.795 + 0.5;    // 18.0 for a 22 mm d20

/* [Deck box interior -- Ultimate Guard Boulder] */
// Width and height are set by the card footprint and are the SAME across the
// Boulder sizes (60+/80+/100+/133+); only the depth budget changes.
box_int_w = 68.5;       // interior width  (across the cards)
box_int_h = 93.0;       // interior height (up the cards)
// The slab's height is set from the SLEEVE, not from the box interior, and
// that is the more trustworthy of the two numbers. box_int_h is a reported
// figure rather than a published spec, but an Ultimate Guard Katana standard
// sleeve is 66 x 91 mm and every deck in the box is that tall. So the rule is
// simply: if your sleeved cards stand up in the box, this does too.
//
// It also puts the slab's top edge level with the top of the cards instead of
// 3 mm below it, which is the point -- the insert stops sinking away from the
// opening and is easier to get a finger to.
// The sleeve is the REFERENCE both slab dimensions are stated against, which
// is what keeps them honest: the height is exactly a sleeve, the width is a
// sleeve plus over_w. Before this they came out of box_int_w - fit_gap_w and
// happened to land on 66 mm, which read as intent and was coincidence -- it
// would have drifted silently the moment either of those was edited.
sleeve_w  = 66.0;       // Ultimate Guard Katana, standard size
sleeve_h  = 91.0;
// ...and then a millimetre wider than the sleeve, deliberately. The slab does
// not have to fit BESIDE a card, only inside the box, and the box is 68.5 mm
// across. Every millimetre here lands in the cavity field, where it widens the
// gaps you get a finger into.
//
// This is the one dimension where the reported box interior is load-bearing:
// the height is bounded by the sleeve, which is a published figure, but the
// width is bounded only by box_int_w. At over_w = 1.0 there is 0.75 mm of
// clearance per side, so a box 1 mm narrower than reported still fits and one
// 1.5 mm narrower does not. Set it back to 0 to sit exactly on the sleeve.
over_w    = 1.0;
box_int_d = 67.5;       // interior depth  (the card stack) -- 100+; reference only
fit_gap_w = box_int_w - sleeve_w - over_w;   // whatever is left over: 1.5 mm
fit_gap_h = box_int_h - sleeve_h;   // whatever is left over: 2.0 mm

/* [Slab] */
slab_depth    = 0;      // 0 = auto/minimum for the chosen profile.
wall          = 2.5;    // OUTER wall. Do not thin this: the lid groove cuts
                        // lid_groove_depth (1.2) into it, leaving only 1.3 mm.
// Divider between two bands. It carries no structural load -- it only separates
// cavities -- so it runs thinner than the perimeter to buy layout space.
// NOT usable for the last band's gap: that divider carries the detent bump,
// whose footprint is 2.30 mm across and would overhang a thinner wall.
div_wall      = 1.6;
// Material behind the deepest cavity. 0.8 is four layers at 0.20 mm, laid
// straight onto the build plate, and nothing loads it in bending -- a die rests
// on it in compression and is pushed out through the hole in it.
floor_t       = 0.8;
// Material above the lid groove. Zero, deliberately: the groove is a DOVETAIL
// -- the lid is trapezoidal and wide at its base, so what stops it lifting out
// is the taper of the groove beside it, not any material on top of it. Running
// the groove all the way to the top face therefore costs nothing, brings the
// lid flush with the frame, and takes 1.4 mm straight off the slab.
cap_t         = 0.0;
corner_relief = 3.0;    // 45 deg chamfer on the four vertical corners
// Solid rail at the top edge, holding the finger scoop. This is the single
// largest lump of material in the part -- 66 x rail x 18.8 of solid -- so it is
// kept only as deep as the scoop needs. scoop_depth (6.0) plus a 2 mm beam
// under it is the floor; below that the beam you hook a finger against when
// lifting the slab out gets too thin to trust.
top_rail      = 7.0;

/* [Layout] */
// The open bay is one undivided space by default. Setting this true splits it
// with a centre rib, which gives the lid a mid-span support -- at the cost of
// turning one usable pocket into two narrow ones. The lid is captured in the
// side grooves along its whole length, so it does not need the rib.
bay_rib   = false;      // centre rib across the open bay
lead_in   = 0.6;        // chamfer at the mouth of each cavity

/* [Push-out holes] */
// A hole through the floor behind every cavity: push a die or a counter stack
// out from behind instead of trying to pick it out. Sized as large as the
// retaining ledge allows, capped at a comfortable fingertip.
// The hole is sized FROM the cavity, not to a fixed number. A flat cap made the
// hole behind a 38.8 mm coin the same size as the one behind a 17.8 mm counter
// well, which left the coin sitting on a 12.4 mm ledge with a fingertip-sized
// hole in the middle of it -- you could push it, but not tip it.
pushout_frac  = 0.80;   // hole diameter as a fraction of the cavity
pushout_ledge = 1.6;    // minimum ledge, per side, measured on the CAVITY. Takes
                        // over on small cavities, where the fraction would leave
                        // too little floor. ~1.2 mm under an actual counter.
pushout_d     = 0;      // optional absolute cap; 0 = none
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

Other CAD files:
dist/models-3mf/Deckblock_Dice_2-lid.3mf
preview.scad
dist/models-stl/Deckblock_DiceAndCoin_1-body.stl
dist/models-stl/Deckblock_DiceAndCoin_2-lid.stl
dist/models-stl/Deckblock_Dice_1-body.stl
dist/models-stl/Deckblock_Dice_2-lid.stl
dist/source/preview.scad

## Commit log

2026-09-03 Parametric TCG deck-box insert: source, release bundle and docs
    Single parametric OpenSCAD source producing three layouts (MTG, Pokemon,
    Riftbound) as a 66 x 88 x 18.6 mm slab that fills the dead space in front of
    a deck, leaving 48.9 mm for cards.
    Design notes:
    - Depth budget is the whole design; 16.0 of the 18.6 mm is the die itself.
    - Dovetail lid groove, so cap material above the groove is redundant
    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
    [BoulderInsert_MTG_1-body.3mf, BoulderInsert_MTG_1-body.stl, BoulderInsert_MTG_2-lid.3mf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]
2026-09-04 Take the slab's height from the sleeve, not the box: 88 -> 91 mm
    The height was derived as box_int_h - fit_gap_h, which leans on box_int_h --
    and that is a reported figure, not a published spec. The README already said
    so. An Ultimate Guard Katana standard sleeve is 66 x 91 mm, and every deck in
    the box is that tall, so the sleeve is the more trustworthy number and the fit
    test becomes something a buyer can actually perform: if your sleeved cards
    stand up in the box, so does this.
    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
    [BoulderInsert_MTG_1-body.3mf, BoulderInsert_MTG_1-body.stl, BoulderInsert_MTG_2-lid.3mf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]
2026-09-04 Two variants on the slide version too: coin and no coin
    Unifies the whole project down to two models. The layouts were named after
    games for three releases and it was always slightly a lie -- nothing in any of
    them is game-specific, and people picked the wrong one because they picked by
    the name on the box instead of by what they actually carry.
    nocoin 6 dice and a 43.8 mm open bay (was "mtg")
    coin 7 dice and a 38 mm flip-coin well (was "pokemon", rebuilt)
    Riftbound is gone. Its layout was a real reading of that game but not a
    different SHAPE of insert -- a third body to print, photograph and support for
    no geometric reason. Its research notes go with it; git history ke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
    [BoulderInsert_DiceAndCoin_1-body.3mf, BoulderInsert_DiceAndCoin_1-body.stl, BoulderInsert_DiceAndCoin_2-lid.3mf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]
2026-09-04 Widen the slab by 1 mm: 66 -> 67
    The slab does not have to fit beside a card, only inside the box, and the box
    is 68.5 mm across. Every millimetre of that lands in the cavity field, where it
    widens the gaps you get a finger into: 5.3 -> 5.8 mm between dice on the no-coin
    layout, 5.4 -> 6.4 mm beside the coin.
    Stated as `over_w = 1.0` -- a deliberate deviation from the sleeve -- rather
    than by editing fit_gap_w, so the sleeve stays the reference both dimensions are
    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
    [BoulderInsert_DiceAndCoin_1-body.3mf, BoulderInsert_DiceAndCoin_1-body.stl, BoulderInsert_DiceAndCoin_2-lid.3mf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]
2026-09-04 Stamp v1.1
    Version marker in the source header and a changelog note in the README, so a
    downloaded .scad says which release it is without needing the repo.
    v1.1 is v1.0 with: the slab at 67 x 91 mm -- height taken from the Katana
    sleeve so the fit test is "do your sleeved cards stand up in the box", width
    a millimetre over it -- and two variants, coin and no coin, in place of three
    game layouts. The lid, groove and detent are unchanged from v1.0.
    [BoulderInsert_DiceAndCoin_1-body.3mf, BoulderInsert_DiceAndCoin_2-lid.3mf, BoulderInsert_Dice_1-body.3mf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]
2026-09-15 Rename project from 'TCG Deck-Case Spacer Inserts' to 'deckblock'
2026-09-15 rename the insert to deckblock: one version, made for the boulder, universal by arithmetic
    tall is the original now, so every version reference is gone: the v1.0/v1.1 note, the
    regression check against a source that was already deleted, the deleted-files row, and
    the changelog in the scad header. the framing is the one you asked for, made to fit an
    ultimate guard boulder 100+ and universal because width and height come off the card
    footprint. dice_insert.scad is deckblock.scad and the models ship as Deckblock_*.
    upload.md is gone, the repo keeps the files, the source and the explanation.
    five things in the docs were wrong, not just old, and re-measuring found them. body
    volumes were 30.8 an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
    [BoulderInsert_DiceAndCoin_1-body.3mf, BoulderInsert_DiceAndCoin_2-lid.3mf, BoulderInsert_Dice_1-body.3mf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]
2026-09-22 re-add the print photos with exif stripped
    the originals carried gps from the iphone that took them, accurate to about
    8 m, which put my home address in a public repo for 2.5 weeks. the pixels are
    unchanged apart from the orientation tag being applied before the metadata was
    dropped, so nothing appears rotated. the old blobs are gone from history, not
    just from the tree.
